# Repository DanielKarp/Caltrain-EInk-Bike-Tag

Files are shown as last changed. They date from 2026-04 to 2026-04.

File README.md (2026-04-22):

# E-Ink Bike Tag for Caltrain

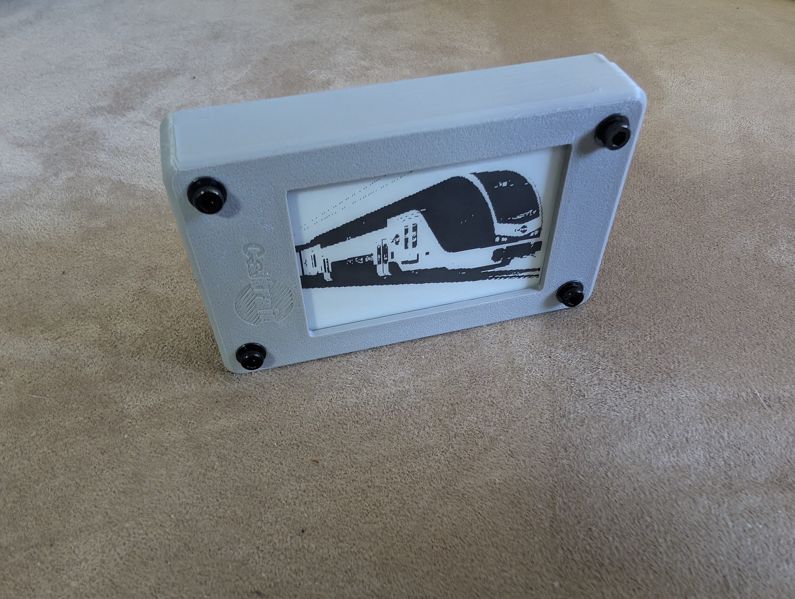
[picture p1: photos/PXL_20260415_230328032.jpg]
Bike Tag Photo
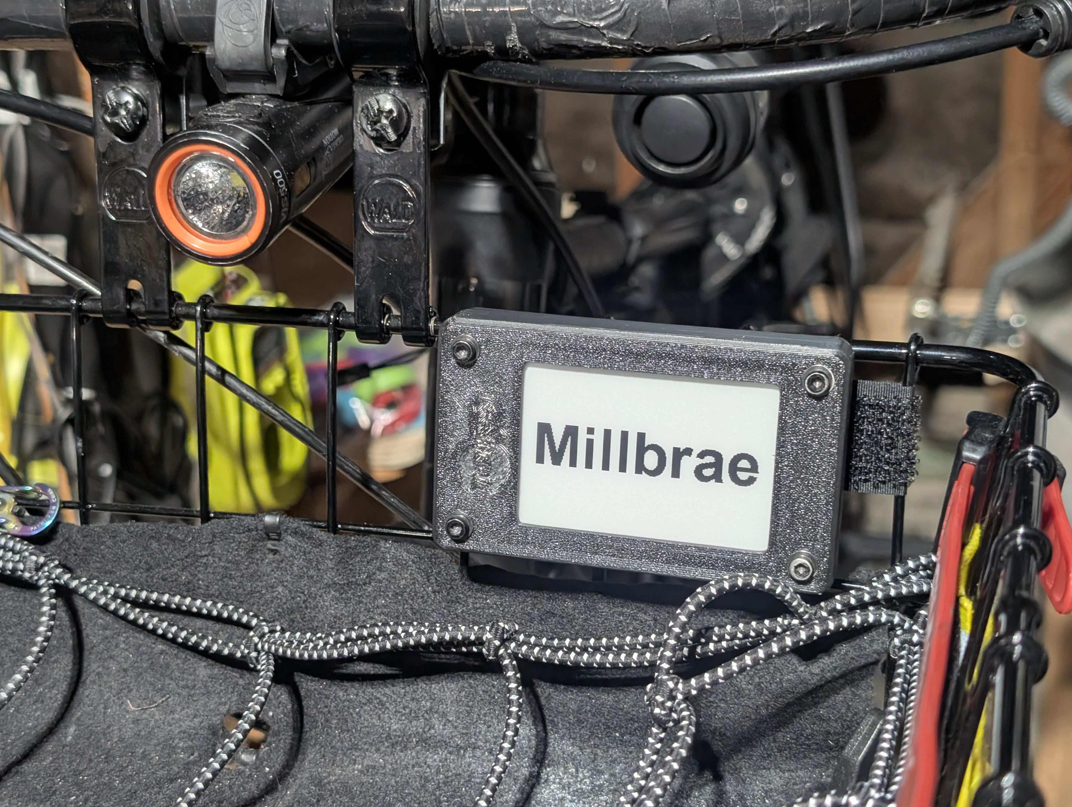
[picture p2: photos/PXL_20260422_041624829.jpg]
Bike Tag Photo 2
 

## What is this project?

A 3D-printed case for an e-ink display and an accompanying Android app that makes it quick and easy to update your destination when you ride Caltrain with a bike.

## Why is this project?

This project was inspired by my ridership patterns on Caltrain - fairly frequent, but rarely consistent. Normal bike tags never really worked for me - I live between two stations on a zone boundry, so I will go to whichever one saves me a few dollars. My destinations also varied as I mostly used Caltrain for non-commuting purposes. When I saw [this reddit post](https://www.reddit.com/r/caltrain/comments/1mhx5lh/i_made_a_programmable_bike_tag/) by u/BruceHalperin I was inspired to get the e-ink display. However, I wanted to build a case that would allow the bike tag to stay securely attached to my bike while keeping it protected; this seemed like a great opportunity to get into 3D printing. I was also not a fan of the app Waveshare provides to write content to the display as it was clunky and not well-suited for quickly writing a station a name to the display, as you had to type in the text each time. When I saw that Waveshare provides an Android SDK, I saw an opportunity to learn a little bit about Android development.

## Project Components

### [The Display](<e-ink display/README.md>)

The display is a Waveshare 2.7" parasitic-NFC-powered e-ink display. It uses power from your phone via NFC and updates the content on the screen. The resolution of 264 x 176 pixels is enough for a few lines of text.

Waveshare Display

### [The Case](case/README.md)

I designed a 3D-printed case in Autodesk Fusion based on measurements of the e-ink display PCB and specifications from Waveshare's website. The case consists of a top lid and bottom base secured with an M3×20mm screw, nut, and washers that hold the PCB against the lid. Press-fit nuts embedded in the base hold everything together (I used gentle heat to make insertion easier, because I did not have any heat-set inserts on hand). The base also includes two slots for a velcro strap to secure the case to a bike.

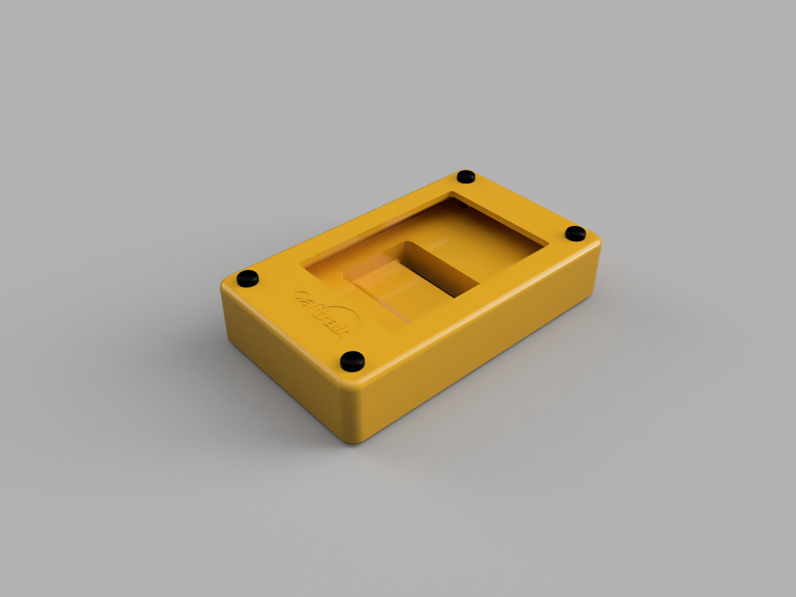
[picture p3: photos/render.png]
Case Render


### [The App](android_app/README.md)

The app provides a simple interface: scroll through a list of stations, select one, and tap the display to update it. I pre-generated the images to keep the app simple and performant, which reduces flexibility but keeps it quick and easy to use. The Waveshare app is still available if you need custom text or images, or you can create your own BMPs and recompile the app. Currently, the app is installed via the Android Studio debug interface; building a distribution APK is left as an exercise for the reader (or future me).

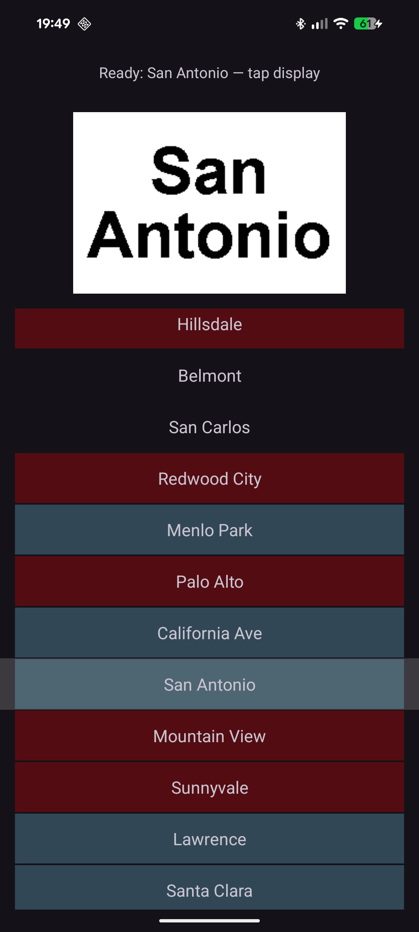
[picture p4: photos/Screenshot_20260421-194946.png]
App Screenshot


#### [BMP Generator](bmp_generator/README.md)

I also wrote a simple BMP Generator to make images for the app, which reads YAML file of station names (with a few attributes) to create BMPs in the right size and name them appropriately. You can create BMPs however you would like, but this way works well for the Caltrain station list.

## Notes

### AI Disclosure

I used AI to help me with most aspects of this project, especially the app development. However, I was involved in every step and reviewed (as best I could) all the code.

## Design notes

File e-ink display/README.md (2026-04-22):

# The Display

The display is a Waveshare 2.7" parasitic-NFC-powered e-ink display. It uses technology similar to wireless charging to power itself when in range of your phone and updates the screen to the data that is shared to it via NFC. The whole writing process takes a few seconds, and there are no batteries to charge. The display I bought use Version 2, Revision 2.2. This is apparently the latest version which has new chips that make the transfer faster, but it means the SDK that Waveshare provides does not work. They do have an app (Android and iOS) that allows you to write content to the screen, either by typing text or by using an image from your phone, but it is not the most intuitive. I had to write my own implementation to communicate with the display and transfer data

## Links

[Waveshare Website](https://www.waveshare.com/wiki/2.7inch_NFC-Powered_e-Paper_Module)

[Amazon Link](https://www.amazon.com/dp/B08B3RG439)

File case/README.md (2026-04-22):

# 3D Printed Case

## Print Settings

Both parts are printed with the outside flat face down for a consistent surface finish.

| Setting | Value |
| --- | --- |
| Material | PLA |
| Nozzle | 0.4mm |
| Layer height | 0.2mm |
| Infill | 25% |
| Walls | 4 |

## Assembly

1. **Insert the nuts into the base.** Warming the nuts slightly using your printer's heated bed makes the press-fit easier.
2. **Thread a velcro strap, zip tie, or other fastener** through the slots in the base.
3. **Attach the PCB to the top half of the case.**
   - Note that the screen is not centered on the PCB — make sure it's oriented correctly before tightening.
   - Use an M3 × 20mm bolt with a washer under the bolt head and another washer between the nut and the PCB.
   - Finger-tighten only — do not overtighten.
4. **Join the base and top halves**, then tighten the bolts until they engage the embedded nuts. Snug is enough — stop before they feel tight.

## Notes

The nuts you use may have slightly different external dimensions than mine, so you may need to modify the hexagonal cutout to fit your hardware. Alternatively, you could use a cap nut with a slightly longer bolt.

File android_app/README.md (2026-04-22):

# E-Ink Bike Tag

<video width="400" controls>
  <source src="../photos/screen-20260421-202834-1776828503225~2.mp4" type="video/mp4">
</video>

An Android application designed to update E-Ink displays (tags) via NFC. It allows users to select from a library of preloaded bitmap images and "flash" them onto a compatible electronic paper display.

## How to Use

1. **Prepare Images**: Place your `.bmp` files in the `app/src/main/assets/images` directory.
2. **Naming Convention**: The app parses filenames to determine the display name and an optional highlight color in the list.
    * **Format**: `[SortIndex]_[OptionalColor]_[Name].bmp`
    * **Examples**:
        * `01_R_Foo.bmp` -> Displays as "Foo" with a **Red** highlight.
        * `02_B_Bar Baz.bmp` -> Displays as "Bar Baz" with a **Blue** highlight.
        * `03_Example.bmp` -> Displays as "Example" with no highlight.
    * **Supported Color Codes**: `R` (Red), `O` (Orange), `Y` (Yellow), `G` (Green), `B` (Blue), `I` (Indigo), `V` (Violet).
3. **Select an Image**: Launch the app and tap an item in the list. A preview of the image will appear at the top.
4. **Write to Tag**: 
    * Ensure NFC is enabled on your device.
    * Hold the back of your phone against the E-Ink display.
    * Keep the device steady while the progress percentage updates.
    * The app will provide a success tone and vibration once the transfer is complete.

## How It Works

* **Asset Management**: On startup, the app scans the `assets/images` folder, parsing the naming convention to build a list of `ImageItem` objects.
* **UI/UX**: Uses a `RecyclerView` for the image list with custom highlights based on the filename metadata. When an item is selected, the list automatically adjusts to keep the selection visible.
* **NFC Communication**:
  * Uses `NfcAdapter.enableReaderMode` to detect tags.
  * Uses a custom `EpdWriter` class to handle the low-level NFC communication (IsoDep) required to transfer bitmap data to the display's flash memory.
* **Feedback**: Integrates `ToneGenerator` and `Vibrator` services to provide immediate haptic and audible feedback for both successful writes and errors.

## Technical Details

* **Language**: Kotlin
* **UI**: XML Layouts with `ComponentActivity`
* **Dependencies**: AndroidX, Material Design, RecyclerView

## Driving the Waveshare NFC E-Ink Display

Getting the Waveshare 2.7" NFC e-paper display to work from Android turned out to be a journey through several layers of the stack.

The obvious starting point was Waveshare's own Android SDK JAR. The main handler class is package-private with obfuscated method names, so we wrapped it in a thin `WaveShareHandler` class to expose a clean interface. This worked for the older tag firmware, but the new tag revision the hardware shipped with wasn't supported by the SDK.

With the SDK ruled out, Waveshare provided the raw driver command specification directly. We wrote `EpdWriter` to implement these commands from scratch. The first attempt used `NfcA.transceive()` — the low-level ISO 14443-3 interface — but every single command failed immediately with `TagLostException`. After ruling out timing and power-harvesting issues, the real problem became clear: the commands are structured as ISO 7816-4 APDUs (`CLA INS P1 P2` format), which need to go through `IsoDep`, not `NfcA`. Switching the transport layer fixed the communication entirely.

The display sequence itself then needed two more corrections. The hardware reset command (`RST LOW`) kills the NFC interface from the inside — it literally resets the chip providing RF power — so it has to be skipped entirely when operating over NFC. And the bitmap pipeline needed fixes on three fronts: color inversion (1=black, not white), 90° rotation (the controller scans in portrait orientation despite the landscape physical layout), and LSB-first bit packing within each byte rather than MSB-first.

Once all of that was sorted, the full init → image transfer → busy-poll refresh cycle completed cleanly in about 4 seconds over NFC.

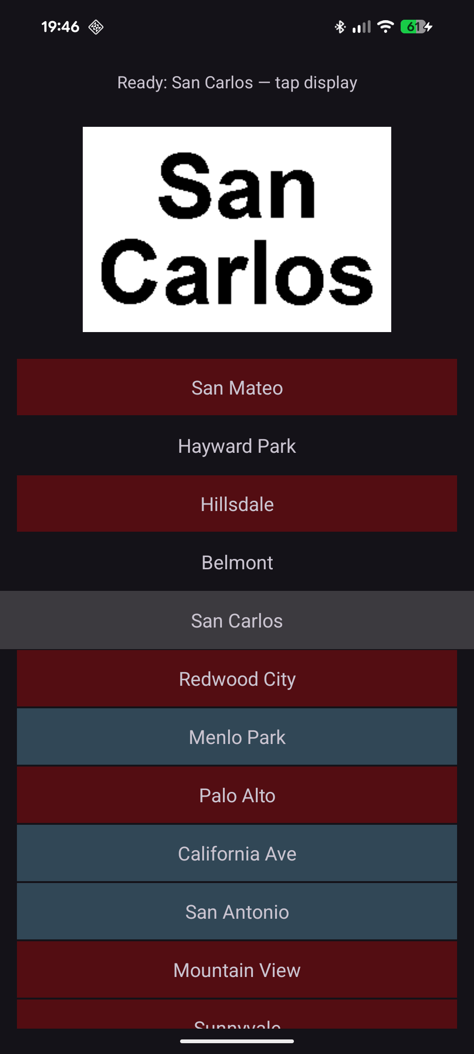
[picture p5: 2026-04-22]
photos/Screenshot_20260421-194636.png

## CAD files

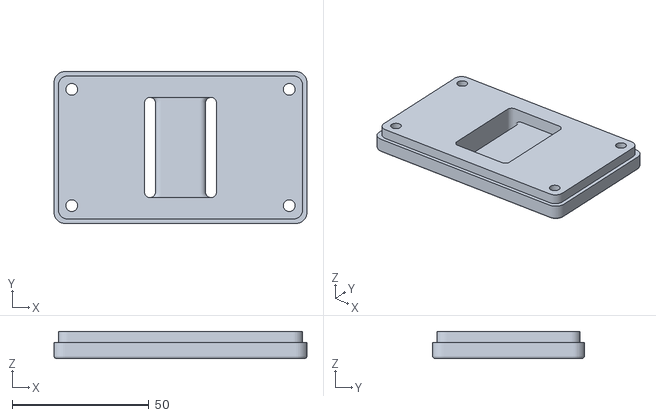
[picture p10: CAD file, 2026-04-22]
case/Bike Tag Case Bottom.stl
92.5 x 55.5 x 10.0

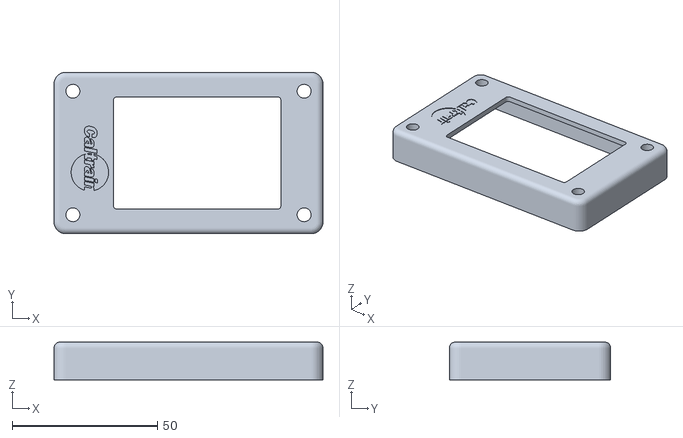
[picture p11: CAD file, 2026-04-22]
case/Bike Tag Case Top.stl
92.5 x 55.5 x 13.0

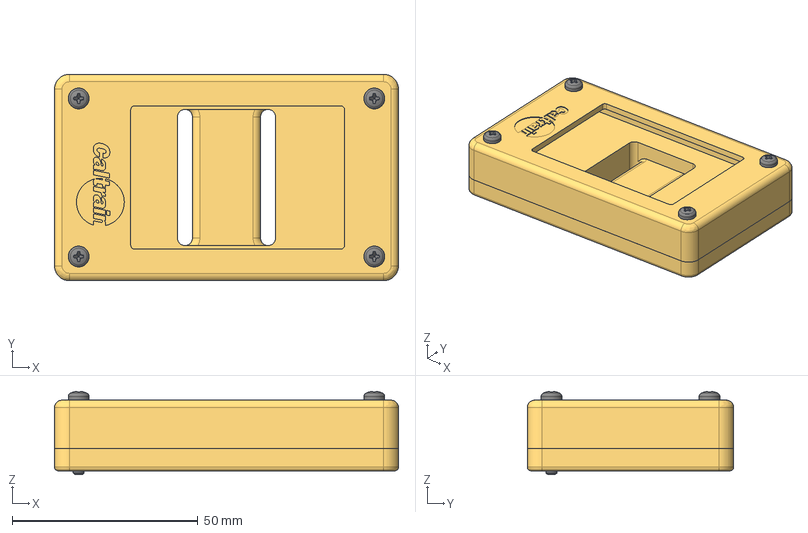
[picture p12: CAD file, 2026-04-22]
case/BIke Tag Case.step
92.5 x 55.5 x 22.3 mm
Main Body
Lid
CRPHMSTI ANSI B18.6.7M - M3x0.5 x 20 Steel Grade 2 Black
CRPHMSTI ANSI B18.6.7M - M3x0.5 x 6 Steel Grade 2 Black x 3
DIN 934 - M3 x 0.5 Steel 6 Plain
DIN 934 - M4 x 0.7 Steel 6 Plain x 3

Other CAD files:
case/BIke Tag Case.stl

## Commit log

2026-04-22 Initial public release
    [BIke Tag Case.step, BIke Tag Case.stl, Bike Tag Case Bottom.stl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]
2026-04-22 updated case README
